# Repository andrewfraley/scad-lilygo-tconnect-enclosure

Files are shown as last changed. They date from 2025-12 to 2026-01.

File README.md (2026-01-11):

# LillyGo T-Connect ESP32 Enclosure

3D printable enclosure for the LillyGo T-Connect ESP32 board.

**LilyGo T-connect:** https://amzn.to/3Laaei9

**RJ45 Modules:** https://amzn.to/49rEJbe

**Dupont jumper wires** https://amzn.to/4pwAtx6 (use male to female jumpers to connect between the T-Connect terminal blocks and the rj45 modules)

**Dupont / JST crimping kit** https://amzn.to/4aNlICu (use JST-XH if you need to use the T-Connect header pins, they're too short for dupont)

**Power input connectors** https://amzn.to/49AZXn7 (if using the 12V input instead of USB)

**Inline fuse holders** https://amzn.to/4sBli8F (You probably want to use a 1A fuse if using the 12V input)

**Victron 48V -> 12V converter** https://amzn.to/4aPAysb (To power the t-connect directly from your battery)

## Getting Started

1. **Download OpenSCAD**: Visit [https://www.openscad.org/](https://www.openscad.org/)
2. **Open the file**: Launch OpenSCAD and open the `.scad` file for your chosen version
3. **Use Customizer** (Tall version only): Press `Alt+C` or go to `Window > Customizer` to adjust parameters
4. **Preview**: Press `F5` to preview the model
5. **Render & Export**: Press `F6` to render, then `File > Export > Export as STL...` to save

---

## Short Version

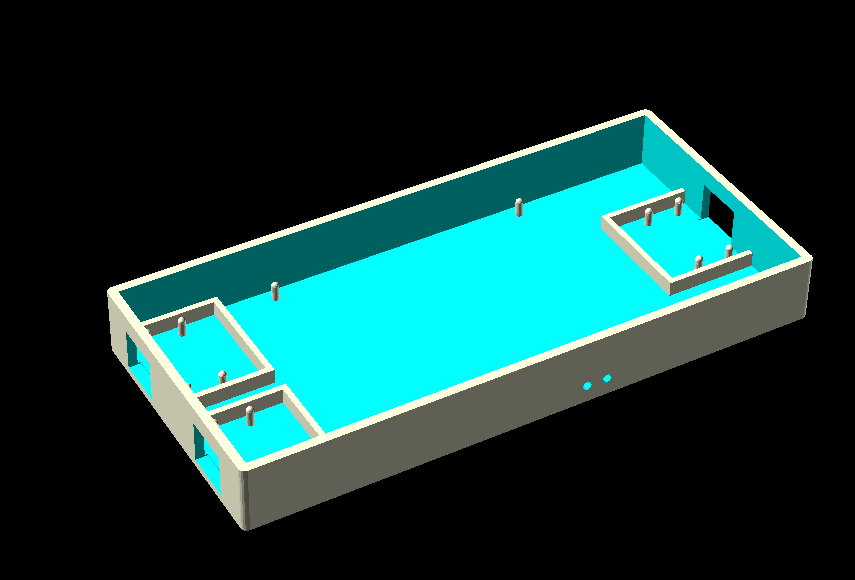
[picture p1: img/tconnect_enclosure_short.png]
Short Enclosure

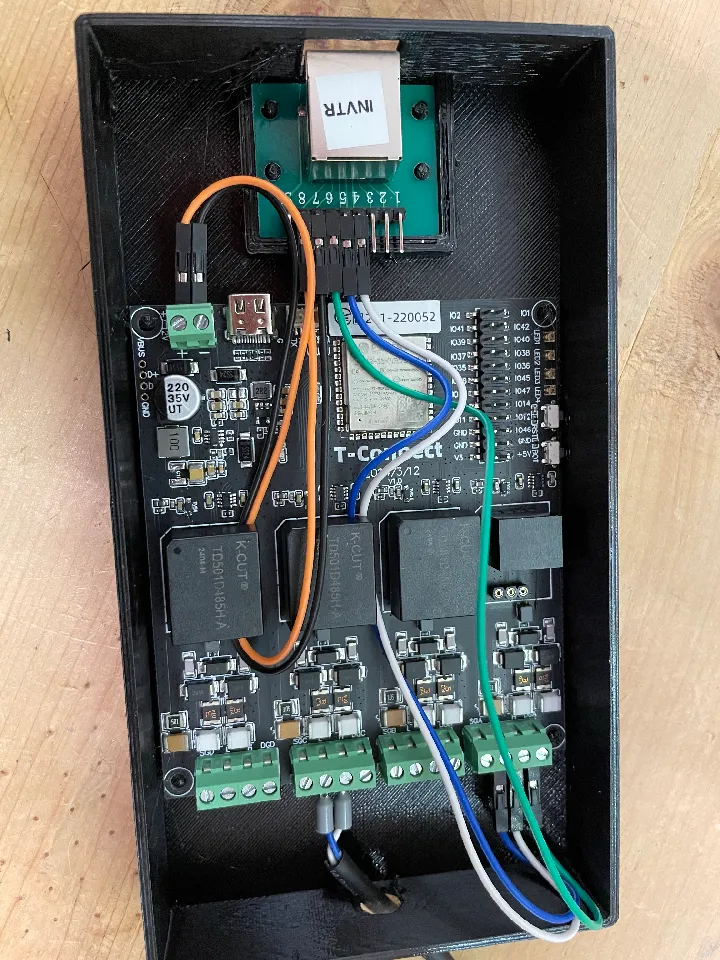
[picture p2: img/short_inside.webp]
Short Enclosure


Simple open shell design with RJ45 modules mounted on the bottom.

**File:** `tconnect_enclosure_short.scad`

### Key Features
- Lower profile (22.5mm wall height)
- RJ45 modules on side walls
- Standard lid with pin guides
- Button holes for board buttons

### Printing & Export
1. Press `F6` to render
2. Go to `File > Export > Export as STL...`
3. Print enclosure and lid separately
4. Recommended: 0.2-0.3mm layer height, 20-30% infill, PLA or PETG

### Fit Adjustments
Edit parameters directly in the SCAD file:
- `lip_clearance`: Clearance between lid and walls (default: 0.2mm) - increase if lid is too tight
- `button1_from_power_side`: Button 1 position (default: 24mm)
- `button2_from_power_side`: Button 2 position (default: 31mm)

---

## Tall Version

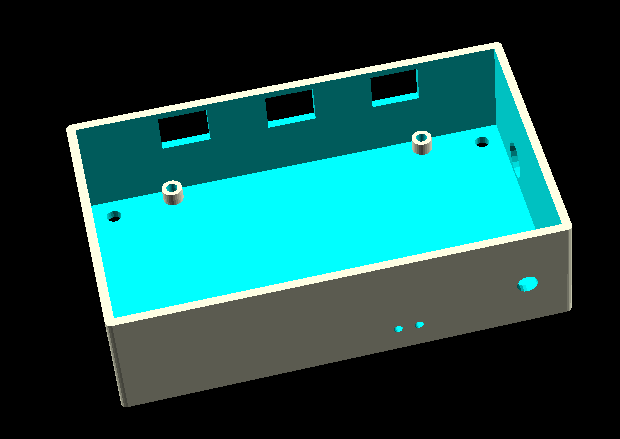
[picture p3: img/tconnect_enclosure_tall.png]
Tall Enclosure

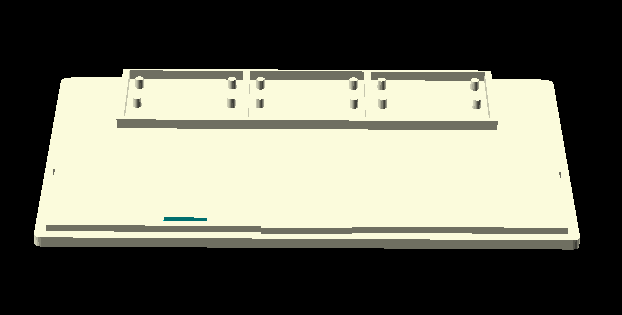
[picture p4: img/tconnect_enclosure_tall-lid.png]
Tall Enclosure

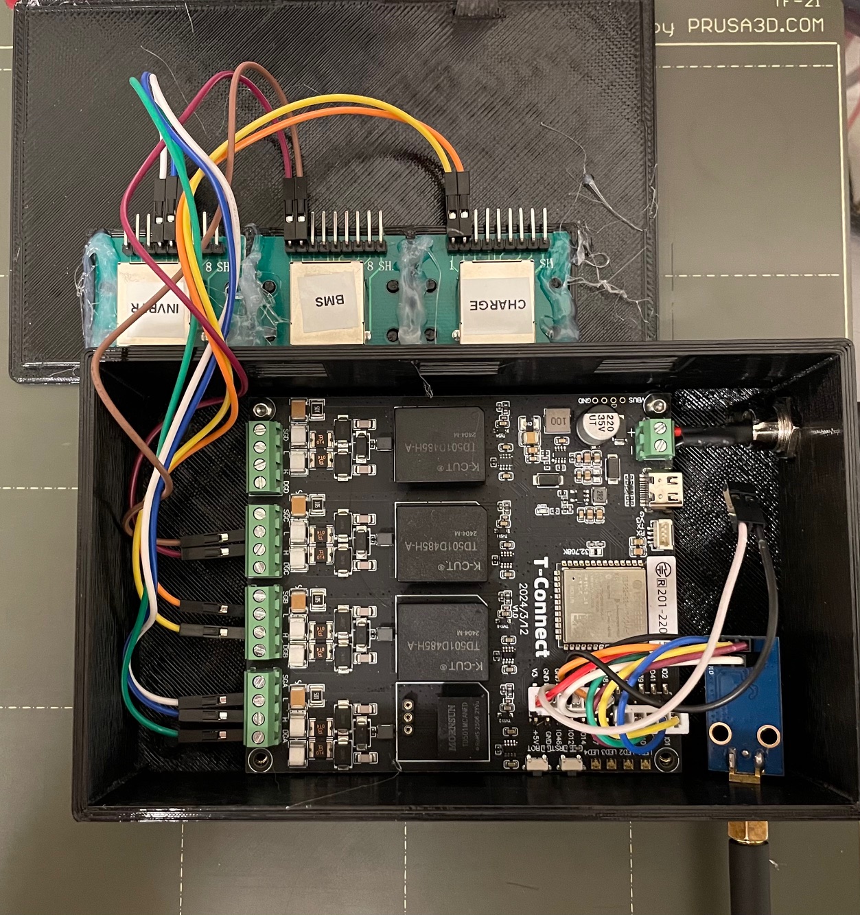
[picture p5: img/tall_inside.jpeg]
Tall Enclosure

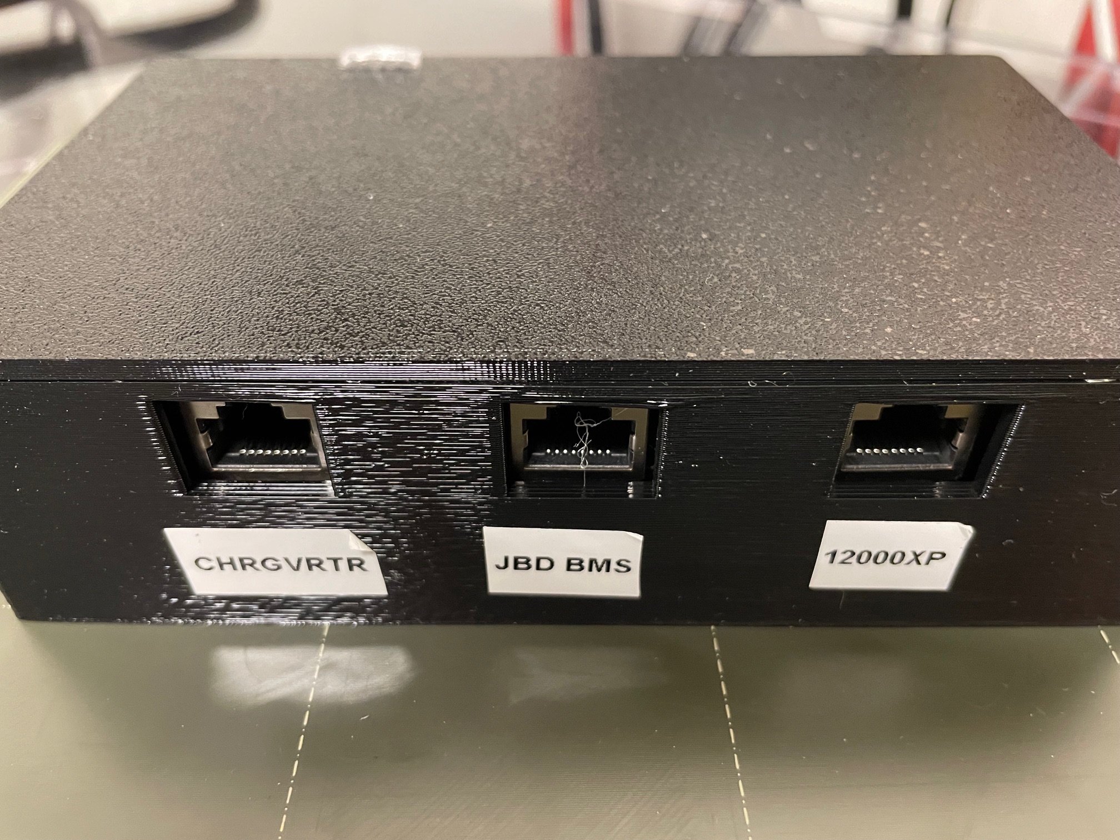
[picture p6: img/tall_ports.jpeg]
Tall Enclosure


Compact design with RJ45 modules mounted inverted in the lid.

**File:** `tconnect_enclosure_tall.scad`

### Key Features
- Taller profile (40mm wall height) for inverted RJ45 modules
- RJ45 modules mounted in lid (more compact footprint)
- Optional power and antenna holes
- Optional wall mounting holes
- LED viewing holes with optional light pipes
- Board mounting: pins or heat inserts

### Key Parameters (via Customizer)

**Rendering Options**
- `render_part`: Choose which part to export (Enclosure, Lid, or Light Pipes)
- `show_lid`: Show lid in preview when rendering enclosure
- `show_light_pipes`: Show light pipes in preview

**Optional Features**
- `enable_power_hole`: Enable/disable power input hole (default: true)
- `enable_antenna_hole`: Enable/disable antenna hole (default: false)
- `enable_mounting_holes`: Enable/disable wall mounting holes (default: true)

**Board Mounting**
- `use_heat_inserts`: Use heat inserts or pins (default: false)
- `board_pin_inset`: Distance from board edge to mount center (default: 3mm)

**RJ45 Modules**
- `rj45_module_count`: Number of modules (default: 3)
- `rj45_module_width`: Internal width (default: 34.5mm)
- `rj45_module_length`: Internal length (default: 29mm)

**Button & LED Holes**
- `button1_from_power_side`: Button 1 position from power side (default: 24mm)
- `button2_from_power_side`: Button 2 position from power side (default: 31mm)
- `led_hole_size`: Size of square LED holes (default: 2mm)
- `led_spacing`: Center-to-center spacing between LEDs (default: 3mm)

**Fit Adjustments**
- `lip_clearance`: Clearance between lid and walls (default: 0.2mm) - increase if lid is too tight
- `snap_tab_depth`: Snap tab interference depth (default: 0.7mm) - adjust if lid is too loose/tight

### Printing & Export
1. Set `render_part` to the component you want (Enclosure, Lid, or Light Pipes)
2. Press `F6` to render
3. Go to `File > Export > Export as STL...`
4. Print each part separately
5. Recommended: 0.2-0.3mm layer height, 20-30% infill, PLA or PETG

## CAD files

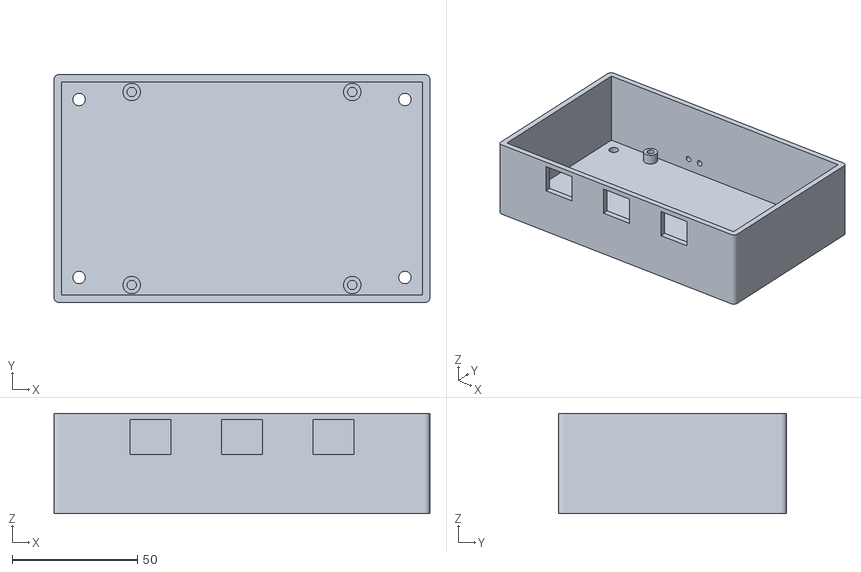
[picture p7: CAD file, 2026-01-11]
tconnect_enclosure_tall_rj45x3.stl
150.0 x 91.0 x 40.0

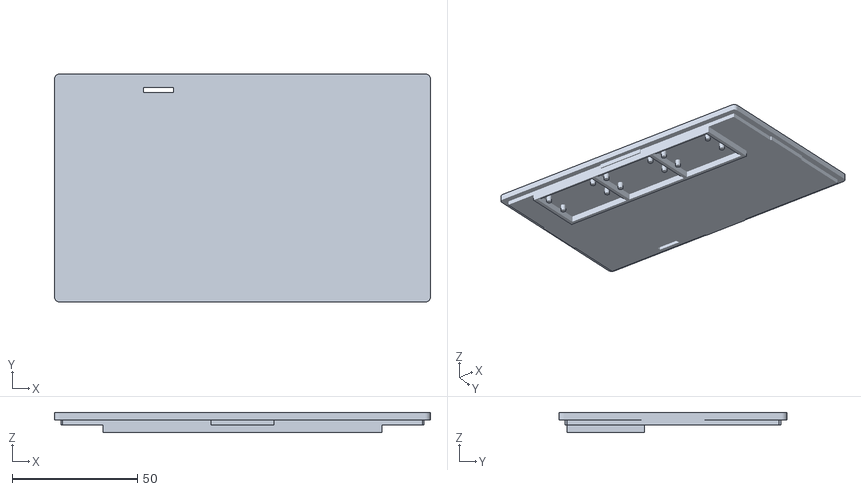
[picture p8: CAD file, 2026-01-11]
tconnect_enclosure_tall_rj45x3-LID.stl
150.0 x 91.0 x 8.00

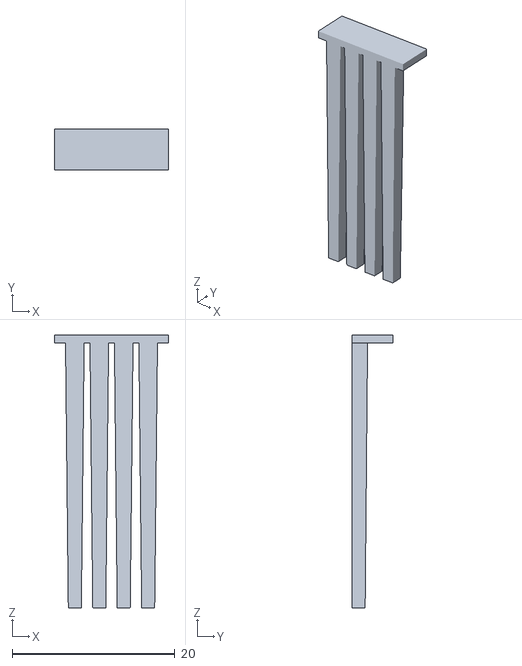
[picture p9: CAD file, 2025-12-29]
tconnect_enclosure_tall_light_pipes.stl
14.0 x 5.00 x 33.5

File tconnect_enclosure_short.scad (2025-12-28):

// LillyGo T-Connect ESP32 Enclosure
// https://lilygo.cc/en-us/products/t-connect
// Open shell for board placement

// Visualization options
show_lid = false; // Show/hide the lid in preview
render_part = "enclosure"; // "enclosure" or "lid" - controls what gets rendered for export

// Board dimensions
board_width = 83;
board_length = 94;
board_height = 13; // Total height with components
board_thickness = 1.6; // Actual PCB thickness
board_clearance = 1;

// Enclosure parameters
wall_thickness = 3;
wall_height = 22.5;
corner_fillet = 2; // Fillet radius for vertical edges

// Lid parameters
lid_thickness = 3; // Thickness of lid top
lip_depth = 2; // How far the lip extends down into the enclosure
lip_clearance = 0.2; // Clearance between lip and enclosure walls
pin_guide_inner_diameter = 2.7; // Inner diameter to fit over pins
pin_guide_outer_diameter = 5; // Outer diameter of pin guides
pin_guide_height = 13; // Height of pin guides - extends to board top (wall_height - pin_height - wall_thickness - board_thickness)

// Clearance dimensions
terminal_clearance = 25;
rj45_connector_width = 16.5; // Width of RJ45 connector cutout
rj45_connector_height = 14; // Height of RJ45 connector cutout
rj45_connector_bottom_offset = 2.5; // Distance from floor to bottom of connector

// Button cutouts
button_diameter = 3; // Diameter of button holes
button_height = 3; // Height from floor to button center
button1_from_power_side = 24; // Distance from power input edge of board to first button
button2_from_power_side = 31; // Distance from power input edge of board to second button

// RJ45 module dimensions
rj45_module_width = 35; // Internal width for RJ45 module
rj45_module_length = 29; // Internal length for RJ45 module
ridge_thickness = 2; // Thickness of ridges around RJ45 modules
ridge_height = 5; // Height of ridges above base

// Calculated RJ45 dimensions (including ridges)
rj45_width = rj45_module_width + 2 * ridge_thickness; // Total width with ridges
rj45_length = rj45_module_length + ridge_thickness; // Total length with one ridge
board_to_rj45_gap = 15; // Gap between main board and RJ45 modules

// Mounting holes
board_holes = 3;
pin_diameter = 2.5;
pin_height = 5;

// Pin placement for RJ45 modules
pin_from_wall = 5; // Distance from wall with opening to first pin pair
pin_from_ridge_side = 3.5; // Distance from side ridges to pins
pin_pair_spacing = 11.5; // Distance between first and second pin pair

// Pin placement for main board
board_pin_inset = 3; // Distance from board edge to pin center

// Calculated dimensions
inner_width = board_width + 2 * board_clearance;
// Extended for RJ45 modules on both sides with gaps
inner_length = rj45_length + board_to_rj45_gap + board_clearance + board_length + board_clearance + board_to_rj45_gap + rj45_length;
outer_width = inner_width + 2 * wall_thickness;
outer_length = inner_length + 2 * wall_thickness;

// Module to create a pin with a rounded top
module rounded_pin(diameter, height) {
  cylinder(d=diameter, h=height, $fn=20);
  translate([0, 0, height])
    sphere(d=diameter, $fn=20);
}

// RJ45 module mount (ridges + pins for one module)
// base_x, base_y: bottom-left corner of the RJ45 module area
// rotation: 0 for wall on +X side (terminal block), 180 for wall on -X side (power input)
module rj45_module_mount(base_x, base_y, rotation) {
  if (rotation == 0) {
    // Terminal block side: wall is on +X side
    // Three ridges (excluding wall side)
    // Left side ridge
    translate([base_x, base_y, wall_thickness])
      cube([ridge_thickness, rj45_width, ridge_height]);
    // Top side ridge
    translate([base_x, base_y + rj45_width - ridge_thickness, wall_thickness])
      cube([rj45_length, ridge_thickness, ridge_height]);
    // Bottom side ridge
    translate([base_x, base_y, wall_thickness])
      cube([rj45_length, ridge_thickness, ridge_height]);

    // Four mounting pins (measured from inner edge of ridges)
    translate([base_x + rj45_length - pin_from_wall, base_y + ridge_thickness + pin_from_ridge_side, wall_thickness])
      rounded_pin(pin_diameter, pin_height);
    translate([base_x + rj45_length - pin_from_wall, base_y + rj45_width - ridge_thickness - pin_from_ridge_side, wall_thickness])
      rounded_pin(pin_diameter, pin_height);
    translate([base_x + rj45_length - pin_from_wall - pin_pair_spacing, base_y + ridge_thickness + pin_from_ridge_side, wall_thickness])
      rounded_pin(pin_diameter, pin_height);
    translate([base_x + rj45_length - pin_from_wall - pin_pair_spacing, base_y + rj45_width - ridge_thickness - pin_from_ridge_side, wall_thickness])
      rounded_pin(pin_diameter, pin_height);
  } else {
    // Power input side: wall is on -X side
    // Three ridges (excluding wall side)
    // Right side ridge (away from wall, toward main board)
    translate([base_x + rj45_length - ridge_thickness, base_y, wall_thickness])
      cube([ridge_thickness, rj45_width, ridge_height]);
    // Top side ridge
    translate([base_x, base_y + rj45_width - ridge_thickness, wall_thickness])
      cube([rj45_length, ridge_thickness, ridge_height]);
    // Bottom side ridge
    translate([base_x, base_y, wall_thickness])
      cube([rj45_length, ridge_thickness, ridge_height]);

    // Four mounting pins (measured from inner edge of ridges)
    translate([base_x + pin_from_wall, base_y + ridge_thickness + pin_from_ridge_side, wall_thickness])
      rounded_pin(pin_diameter, pin_height);
    translate([base_x + pin_from_wall, base_y + rj45_width - ridge_thickness - pin_from_ridge_side, wall_thickness])
      rounded_pin(pin_diameter, pin_height);
    translate([base_x + pin_from_wall + pin_pair_spacing, base_y + ridge_thickness + pin_from_ridge_side, wall_thickness])
      rounded_pin(pin_diameter, pin_height);
    translate([base_x + pin_from_wall + pin_pair_spacing, base_y + rj45_width - ridge_thickness - pin_from_ridge_side, wall_thickness])
      rounded_pin(pin_diameter, pin_height);
  }
}

// Module to create a box with filleted vertical edges
module rounded_box(length, width, height, fillet) {
  hull() {
    // Four corner cylinders for the fillets
    translate([fillet, fillet, 0])
      cylinder(r=fillet, h=height, $fn=20);
    translate([length - fillet, fillet, 0])
      cylinder(r=fillet, h=height, $fn=20);
    translate([fillet, width - fillet, 0])
      cylinder(r=fillet, h=height, $fn=20);
    translate([length - fillet, width - fillet, 0])
      cylinder(r=fillet, h=height, $fn=20);
  }
}

// Main enclosure shell
module enclosure_shell() {
  union() {
    difference() {
      // Outer box with filleted edges
      rounded_box(outer_length, outer_width, wall_height, corner_fillet);

      // Inner cavity
      translate([wall_thickness, wall_thickness, wall_thickness])
        cube([inner_length, inner_width, wall_height]);

      // RJ45 connector cutouts on terminal block side
      // Left RJ45 connector cutout
      translate(
        [
          outer_length - wall_thickness - 1,
          wall_thickness + (rj45_width - rj45_connector_width) / 2,
          rj45_connector_bottom_offset,
        ]
      )
        cube([wall_thickness + 2, rj45_connector_width, rj45_connector_height]);

      // Right RJ45 connector cutout
      translate(
        [
          outer_length - wall_thickness - 1,
          outer_width - wall_thickness - rj45_width + (rj45_width - rj45_connector_width) / 2,
          rj45_connector_bottom_offset,
        ]
      )
        cube([wall_thickness + 2, rj45_connector_width, rj45_connector_height]);

      // Power input side - centered RJ45 connector cutout
      translate(
        [
          -1,
          (outer_width - rj45_connector_width) / 2,
          rj45_connector_bottom_offset,
        ]
      )
        cube([wall_thickness + 2, rj45_connector_width, rj45_connector_height]);

      // Button holes on top side wall (long edge)
      // Button 1
      translate(
        [
          wall_thickness + rj45_length + board_to_rj45_gap + board_clearance + button1_from_power_side,
          outer_width + 1,
          wall_thickness + button_height,
        ]
      )
        rotate([90, 0, 0])
          cylinder(d=button_diameter, h=wall_thickness + 2, $fn=20);

      // Button 2
      translate(
        [
          wall_thickness + rj45_length + board_to_rj45_gap + board_clearance + button2_from_power_side,
          outer_width + 1,
          wall_thickness + button_height,
        ]
      )
        rotate([90, 0, 0])
          cylinder(d=button_diameter, h=wall_thickness + 2, $fn=20);
    }

    // All RJ45 module mounts (ridges + pins)
    // Terminal block side - Left
    rj45_module_mount(
      wall_thickness + rj45_length + board_to_rj45_gap + board_clearance + board_length + board_to_rj45_gap,
      wall_thickness,
      0
    );
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

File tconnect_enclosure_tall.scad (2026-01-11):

// LillyGo T-Connect ESP32 Enclosure - TALL VERSION
// https://lilygo.cc/en-us/products/t-connect
// RJ45 modules mounted inverted in lid for compact length

/* [Rendering Options] */
// Which part to render for export
render_part = "enclosure"; // [enclosure:Enclosure, lid:Lid, light_pipes:Light Pipes]
// Show lid in preview when rendering enclosure
show_lid = false;
// Show lid flush (true) or offset above (false)
lid_flush = false;
// Show light pipes in preview
show_light_pipes = false;

/* [Board Dimensions] */
board_width = 83;
board_length = 94;
board_height = 13; // Total height with components above board
board_thickness = 4; // PCB thickness including underside protrusions
board_clearance = 1; // Clearance in width direction
terminal_block_clearance = 25; // Clearance on length ends

/* [Enclosure Parameters] */
wall_thickness = 3;
wall_height = 40; // Tall version for inverted RJ45 modules
corner_fillet = 2; // Fillet radius for vertical edges

/* [Lid Parameters] */
lid_thickness = 3; // Thickness of lid top
lip_depth = 2; // How far the lip extends down
lip_clearance = 0.2; // Clearance between lip and walls

/* [Snap Tabs] */
snap_tab_width = 25; // Width of each snap tab
snap_tab_depth = 0.7; // How far tab extends inward (creates interference)
snap_tab_height = 2; // Height of tab at bottom of lip

/* [Board Mounting] */
// Use heat inserts or pins
use_heat_inserts = false;
// Distance from board edge to mount center
board_pin_inset = 3;

/* [Mounting Pins] */
pin_diameter = 2.5;
pin_height = 5;

/* [Heat Insert Mounts] */
insert_outer_diameter = 4; // Widest diameter
insert_inner_diameter = 3.4; // Thinnest diameter
insert_height = 4;
mount_height = 5; // Height of post (matches pin height)
mount_diameter = 6; // Diameter of post base

/* [RJ45 Module Configuration] */
rj45_module_count = 3; // Number of modules
rj45_module_width = 34.5; // Internal width (reduced 1mm to close side gaps)
rj45_module_length = 29; // Internal length
ridge_thickness = 2; // Ridge thickness
ridge_height = 5; // Ridge height

/* [RJ45 Connector Cutouts] */
rj45_connector_width = 16.5; // Cutout width
rj45_connector_height = 14; // Cutout height

/* [RJ45 Pin Placement] */
pin_from_wall = 5; // Distance from wall to first pin pair
pin_from_ridge_side = 3.25; // Distance from side ridges
pin_pair_spacing = 11.5; // Distance between pin pairs

/* [Button Holes] */
button_diameter = 3;
button_height = mount_height + 1.5; // Height from floor
button1_from_power_side = 24; // Button 1 position
button2_from_power_side = 31; // Button 2 position

/* [LED Viewing Holes] */
led_hole_size = 2; // Size of square holes (2mm APA102 LEDs)
led_first_from_power_side = 8; // First LED edge position from power side (center at 9mm)
led_spacing = 3; // Center-to-center spacing between LEDs
led_from_bottom_edge = 2.5; // Distance from edge to LED center (1mm edge + 1mm LED center)

/* [Light Pipe Parameters] */
light_pipe_length = 34; // Length from bottom of flange to LED tops (44 - 1 - 11 = 32, +2mm for insertion)
light_pipe_flange_size = 5; // Flange size on lid
light_pipe_flange_thickness = 1; // Flange thickness
light_pipe_taper = 0.1; // Taper for insertion (mm/side)

/* [Power Cable Entry Hole] */
enable_power_hole = true; // [true,false] Enable/disable power input hole
power_hole_diameter = 7; // Diameter (for Cat6)
power_hole_from_led_edge = 8; // Position from edge
power_hole_height = 8; // Height from floor

/* [Antenna Hole] */
enable_antenna_hole = false; // [true,false] Enable/disable antenna hole
antenna_hole_diameter = 7; // Diameter
antenna_hole_height = 8; // Height from floor
antenna_hole_from_power_side = 12.5; // Distance from power side wall inner edge

/* [Wall Mounting Holes] */
enable_mounting_holes = true; // [true,false] Enable/disable wall mounting holes
mounting_hole_diameter = 5;
mounting_hole_inset = 10; // Distance from corners

/* [Hidden] */
// Calculated RJ45 dimensions
rj45_single_width = rj45_module_width + 2 * ridge_thickness;
rj45_row_length = (rj45_module_count * rj45_module_width) + ( (rj45_module_count + 1) * ridge_thickness);

// RJ45 connector cutout positioning
rj45_connector_top_offset = wall_height - 2.5;

// Calculated enclosure dimensions
min_length_for_board = board_length + 2 * terminal_block_clearance;
min_length_for_rj45 = rj45_row_length + 4;
inner_length = max(min_length_for_board, min_length_for_rj45);
inner_width = board_width + 2 * board_clearance;
outer_width = inner_width + 2 * wall_thickness;
outer_length = inner_length + 2 * wall_thickness;

// Unused legacy variable
terminal_clearance = 25;

// Module to create a pin with a rounded top
module rounded_pin(diameter, height) {
  cylinder(d=diameter, h=height, $fn=20);
  translate([0, 0, height])
    sphere(d=diameter, $fn=20);
}

// Module to create a heat insert mount post
module heat_insert_mount() {
  difference() {
    // Mounting post
    cylinder(d=mount_diameter, h=mount_height, $fn=30);
    // Hole for heat insert (sized for press fit, goes all the way through)
    translate([0, 0, -0.1])
      cylinder(d=insert_outer_diameter - 0.2, h=mount_height + 0.2, $fn=30);
  }
}

// Module to create a solid standoff (for pin mounting)
module solid_standoff() {
  cylinder(d=mount_diameter, h=mount_height, $fn=30);
}

// Module for a row of 4 RJ45 modules with shared ridges (inverted for lid)
// base_x, base_y: starting position (left edge of first module)
// Ridges and pins point DOWN from lid
module rj45_row_inverted(base_x, base_y) {
  // Create ridges - one at each end, one between each pair
  for (i = [0:rj45_module_count]) {
    // Vertical ridges perpendicular to the wall
    x_pos = base_x + (i * (rj45_module_width + ridge_thickness));
    translate([x_pos, base_y, -ridge_height])
      cube([ridge_thickness, rj45_module_length, ridge_height]);
  }

  // Create horizontal ridges parallel to the wall (front is 1mm and extended 1mm forward, back is full thickness moved back 1mm)
  translate([base_x, base_y - 1, -ridge_height])
    cube([rj45_row_length, 1, ridge_height]);
  translate([base_x, base_y + rj45_module_length - ridge_thickness + 1, -ridge_height])
    cube([rj45_row_length, ridge_thickness, ridge_height]);

  // Create pins for each module
  for (i = [0:rj45_module_count - 1]) {
    module_x = base_x + ridge_thickness + (i * (rj45_module_width + ridge_thickness));

    // Four pins per module
    translate([module_x + pin_from_ridge_side, base_y + pin_from_wall, -pin_height])
      cylinder(d=pin_diameter, h=pin_height, $fn=20);
    translate([module_x + rj45_module_width - pin_from_ridge_side, base_y + pin_from_wall, -pin_height])
      cylinder(d=pin_diameter, h=pin_height, $fn=20);
    translate([module_x + pin_from_ridge_side, base_y + pin_from_wall + pin_pair_spacing, -pin_height])
      cylinder(d=pin_diameter, h=pin_height, $fn=20);
    translate([module_x + rj45_module_width - pin_from_ridge_side, base_y + pin_from_wall + pin_pair_spacing, -pin_height])
      cylinder(d=pin_diameter, h=pin_height, $fn=20);
  }
}

// Module to create a box with filleted vertical edges
module rounded_box(length, width, height, fillet) {
  hull() {
    // Four corner cylinders for the fillets
    translate([fillet, fillet, 0])
      cylinder(r=fillet, h=height, $fn=20);
    translate([length - fillet, fillet, 0])
      cylinder(r=fillet, h=height, $fn=20);
    translate([fillet, width - fillet, 0])
      cylinder(r=fillet, h=height, $fn=20);
    translate([length - fillet, width - fillet, 0])
      cylinder(r=fillet, h=height, $fn=20);
  }
}

// Main enclosure shell
module enclosure_shell() {
  union() {
    difference() {
      // Outer box with filleted edges
      rounded_box(outer_length, outer_width, wall_height, corner_fillet);

      // Inner cavity
      translate([wall_thickness, wall_thickness, wall_thickness])
        cube([inner_length, inner_width, wall_height]);

      // RJ45 connector cutouts on opposite side from buttons (3 connectors in a row)
      // Center the cutouts to match the centered RJ45 mounts in the lid
      for (i = [0:rj45_module_count - 1]) {
        cutout_x = (outer_length - rj45_row_length) / 2 + ridge_thickness + (i * (rj45_module_width + ridge_thickness)) + (rj45_module_width - rj45_connector_width) / 2;
        translate(
          [
            cutout_x,
            -1,
            rj45_connector_top_offset,
          ]
        )
          rotate([-90, 0, 0])
            cube([rj45_connector_width, rj45_connector_height, wall_thickness + 2]);
      }

      // Button holes on button side wall (long edge) - positioned to avoid RJ45 cutouts
      // Button 1
      translate(
        [
          wall_thickness + terminal_block_clearance + button1_from_power_side,
          outer_width + 1,
          wall_thickness + button_height,
        ]
      )
        rotate([90, 0, 0])
          cylinder(d=button_diameter, h=wall_thickness + 2, $fn=20);
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

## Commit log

2025-12-27 basic setup complete
    [tconnect_enclosure.scad]
2025-12-27 draft version with 3 rj45
    [tconnect_enclosure.scad]
2025-12-27 fix pin insets
    [tconnect_enclosure.scad]
2025-12-28 added button holes
    [tconnect_enclosure.scad]
2025-12-28 close to final
    [tconnect_enclosure.scad]
2025-12-28 added tall version and cursor transcript
    [ExportedParameters.csv, tconnect_enclosure_tall.scad]
2025-12-28 4 rj45
    [tconnect_enclosure_tall.scad]
2025-12-28 four connector version
    [tconnect_enclosure_tall.scad]
2025-12-28 final iteration
    [tconnect_enclosure_tall.scad]
2025-12-28 fix rj45 cutout offset
    [tconnect_enclosure_tall.scad]
2025-12-28 remove pin guide variales
    [tconnect_enclosure_tall.scad]
2025-12-28 added power connector
    [tconnect_enclosure_tall.scad]
2025-12-28 add final STLs
    [tconnect_enclosure_tall.scad, tconnect_enclosure_tall_rj45x3-LID.stl, tconnect_enclosure_tall_rj45x3.stl]
2025-12-28 add light pipes
    [tconnect_enclosure_tall.scad]
2025-12-28 refactor variables and add screw insert support
    [tconnect_enclosure_tall.scad, tconnect_enclosure_tall_light_pipes.stl, tconnect_enclosure_tall_rj45x3-LID.stl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]
2025-12-29 increase minimum width and fix light pipes
    [tconnect_enclosure_tall.scad, tconnect_enclosure_tall_light_pipes.stl, tconnect_enclosure_tall_rj45x3-LID.stl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]
2025-12-29 update STLs
    [tconnect_enclosure_tall_light_pipes.stl, tconnect_enclosure_tall_rj45x3-LID.stl, tconnect_enclosure_tall_rj45x3.stl]
2025-12-29 lower button holes by 1mm
    [tconnect_enclosure_tall.scad]
2025-12-29 fix model
    [tconnect_enclosure_tall_rj45x3.stl]
2025-12-29 fix light pipe taper
    [tconnect_enclosure_tall.scad, tconnect_enclosure_tall_light_pipes.stl]
2025-12-29 add lid tabs
    [tconnect_enclosure_tall.scad, tconnect_enclosure_tall_rj45x3-LID.stl]
2025-12-29 power input hole variables
    [tconnect_enclosure_tall.scad]
2025-12-29 wall mounting holes optional
    [tconnect_enclosure_tall.scad]
2025-12-29 fix lid rj45 mounts
    [tconnect_enclosure_tall.scad]
2025-12-29 adjust light tubes
    [tconnect_enclosure_tall.scad, tconnect_enclosure_tall_light_pipes.stl, tconnect_enclosure_tall_rj45x3-LID.stl]
2025-12-29 move rear ridge back 1mm
    [tconnect_enclosure_tall.scad]
2025-12-29 try to fix ridge mounts
    [tconnect_enclosure_tall.scad]
2025-12-29 open hole for light pipes
    [tconnect_enclosure_tall.scad, tconnect_enclosure_tall_light_pipes.stl, tconnect_enclosure_tall_rj45x3-LID.stl]
2025-12-30 adjust light pipe holes
    [tconnect_enclosure_tall.scad, tconnect_enclosure_tall_rj45x3-LID.stl]
2026-01-11 add antenna hole
    [tconnect_enclosure_tall.scad, tconnect_enclosure_tall_rj45x3-LID.stl, tconnect_enclosure_tall_rj45x3.stl]
2026-01-11 add readme
    [ExportedParameters.csv]
2026-01-11 add images
    [tconnect_enclosure_short.scad]
